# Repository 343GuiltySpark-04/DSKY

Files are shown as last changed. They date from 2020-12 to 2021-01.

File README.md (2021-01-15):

# DSKY

## This is a project where I make a replica of the DSKY (DiSplay and Keyboard assemblY) that works with ReEntry: an orbital simulator.

I am planning to sell these replicas. I have made functional prototypes of the display and keyboard, i just need to design pcb's to merge it all together, which i am currently doing.

## Guide on hooking up the PCB and installing the software

Preperation: hookup your arduino to your PC, download the repo in zip format and extract it, and enable the AGC output function in teh reentry settings (at the bottom).

# Step one: install python

Go to this link:

https://realpython.com/installing-python/

And follow the guide for your respective OS.

# Step two: edit the port.

Right click the JSON_export file, and edit with IDLE. First, check to what port your arduino is plugged in.
You can find the device manager by searching for it in Start. Then select Ports to display the list of ports. It should say Arduino (COMX).

Now, remember what number is behind the port. Go back to the script and edit where it says COM3 into what port yours is (COM1, COM2, etc).

# Step 3: Upload the code onto the arduino

Install the arduino IDE from the arduino website. Next, open the display.ino file from the display folder in the arduino IDE. Now, click on Tools > ports > and select
your correct port (the one you put in the script). Now, click on the upload button in  the top left. When its done, you can close the IDE. To use it now, you can run the python script in IDLE.

# Step 4: Hooking up the PCB

*WIP*

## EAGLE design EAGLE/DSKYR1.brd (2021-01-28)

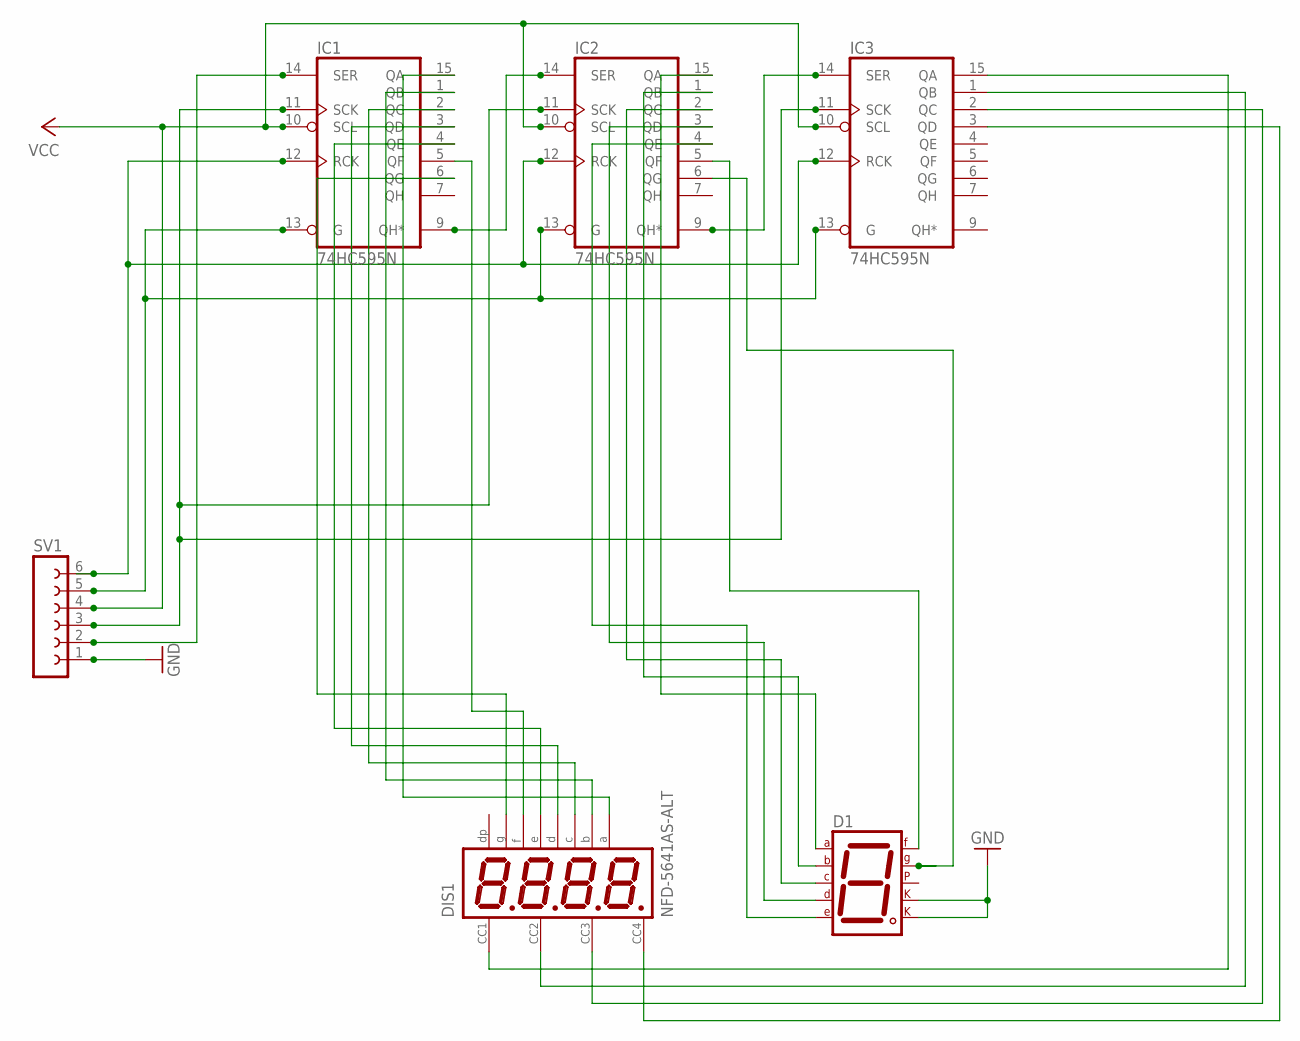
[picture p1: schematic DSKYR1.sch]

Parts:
D1: 7SEG-CK; 7SEG-13
DIS1: NFD-5641AS-ALT; NFD-5641
IC1, IC2, IC3: 74HC595N; DIL16
SV1: FE06-1; FE06

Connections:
GND: D1.3 (CK1), D1.8 (CK2), IC1.8 (GND), IC2.8 (GND), IC3.8 (GND), SV1.1
unnamed: IC1.12 (RCK), IC2.12 (RCK), IC3.12 (RCK), SV1.6
unnamed: DIS1.P$10, IC1.5 (QF)
unnamed: DIS1.P$5, IC1.6 (QG)
unnamed: IC1.13 (G), IC2.13 (G), IC3.13 (G), SV1.5
unnamed: IC1.14 (SER), SV1.2
unnamed: IC1.9 (QH*), IC2.14 (SER)
unnamed: IC1.11 (SCK), IC2.11 (SCK), IC3.11 (SCK), SV1.3
unnamed: IC2.9 (QH*), IC3.14 (SER)
unnamed: DIS1.P$11, IC1.15 (QA)
unnamed: DIS1.P$7, IC1.1 (QB)
unnamed: DIS1.P$4, IC1.2 (QC)
unnamed: DIS1.P$2, IC1.3 (QD)
unnamed: DIS1.P$1, IC1.4 (QE)
unnamed: D1.7 (A), IC2.15 (QA)
unnamed: D1.6 (B), IC2.1 (QB)
unnamed: D1.4 (C), IC2.2 (QC)
unnamed: D1.2 (D), IC2.3 (QD)
unnamed: D1.1 (E), IC2.4 (QE)
unnamed: D1.9 (F), IC2.5 (QF)
unnamed: D1.10 (G), IC2.6 (QG)
unnamed: DIS1.P$12, IC3.15 (QA)
unnamed: DIS1.P$9, IC3.1 (QB)
unnamed: DIS1.P$8, IC3.2 (QC)
unnamed: DIS1.P$6, IC3.3 (QD)
VCC: IC1.10 (SCL), IC1.16 (VCC), IC2.10 (SCL), IC2.16 (VCC), IC3.10 (SCL), IC3.16 (VCC), SV1.4

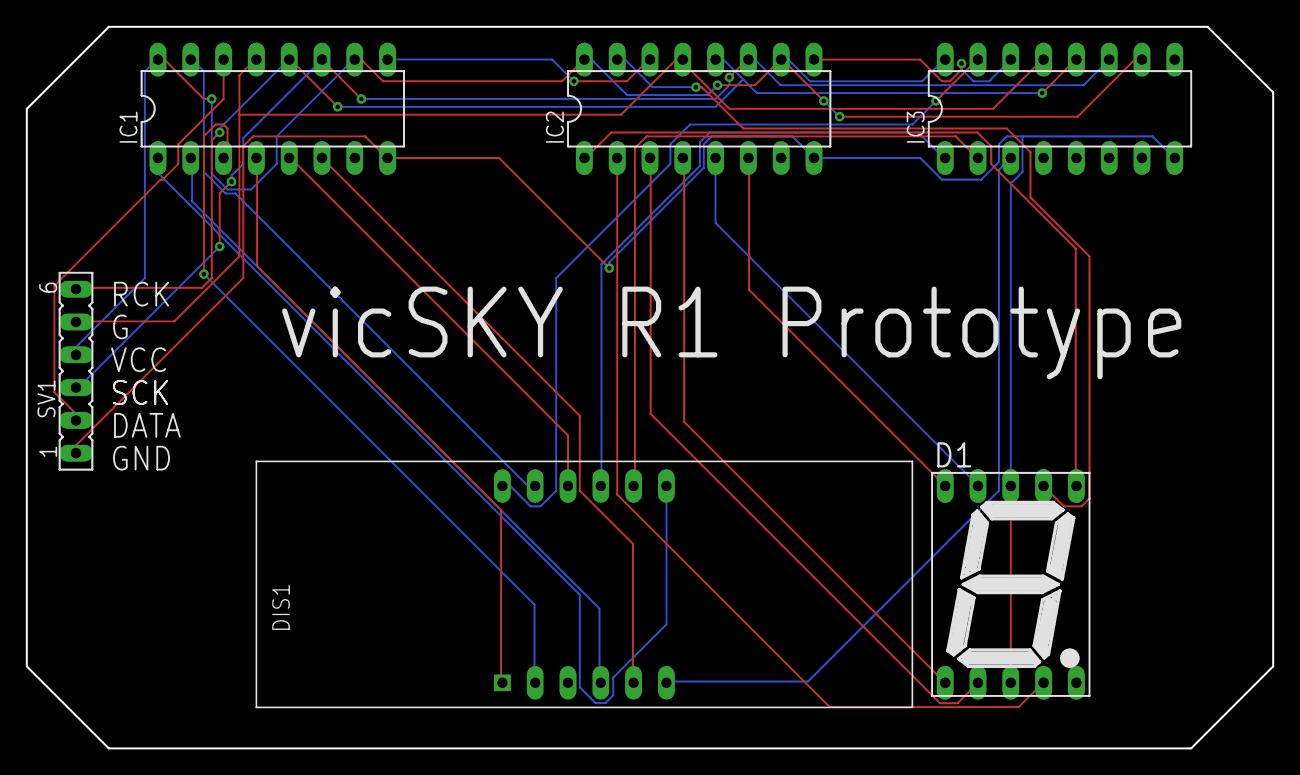
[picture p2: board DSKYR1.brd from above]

Board: 2 copper layers, 96.5 x 55.9 mm, 6 parts (0 on the bottom side), 26 nets.

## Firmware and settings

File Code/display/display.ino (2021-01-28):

int latchPin = 11;
int clockPin = 9;
int dataPin = 12;
byte first;
byte second;
byte third;

char R1D1;
char R1D2;
char R1D3;
char R1D4;
char R1D5;


const byte numChars = 64;
char receivedChars[numChars];

void updateShiftRegister(){
  digitalWrite(latchPin, LOW);
  
  shiftOut(dataPin, clockPin, LSBFIRST, first);
  shiftOut(dataPin, clockPin, LSBFIRST, second);  
  shiftOut(dataPin, clockPin, LSBFIRST, third);  
  digitalWrite(latchPin, HIGH);
}



void setup(){
  pinMode(latchPin, OUTPUT);
  pinMode(dataPin, OUTPUT);
  pinMode(clockPin, OUTPUT);
  Serial.begin(9600);
  
}

void setNumber(char num){
  if (num == '1'){
    third = 0b01100000;
    second = 0b01100000;
  }

  if (num == '2'){
    third = 0b11011011;
    second = 0b11011011;
  }

  if (num == '3'){
    third = 0b11110011;
    second = 0b01100000;
  }

  if (num == '4'){
    third = 0b01100111;;
    second = 0b01100111;;
  }

  if (num == '5'){
    third = 0b10110111;
    second = 0b10110111;
  }

  if (num == '6'){
    third = 0b10111111;
    second = 0b10111111;
  }

  if (num == '7'){
    third = 0b11100001;
    second = 0b11100001;
  }
  if (num == '8'){
    third = 0b11111111;
    second = 0b11111111;
  }
  if (num == '9'){
    third = 0b11100111;
    second = 0b11110111;
  }
  if (num == '0'){
    third = 0b11111101;
    second = 0b11111101;
  }
}


void recvWithStartEndMarkers() {
    static boolean recvInProgress = false;
    static byte ndx = 0;
    char startMarker = '<';
    char endMarker = '>';
    char rc;

    while (Serial.available() > 0) {
        rc = Serial.read();

        if (recvInProgress == true) {
            if (rc != endMarker) {
                receivedChars[ndx] = rc;
                ndx++;
                if (ndx >= numChars) {
                    ndx = numChars - 1;
                }
            }
            else {
                receivedChars[ndx] = '\0'; // terminate the string
                recvInProgress = false;
                ndx = 0;
                
            }
        }

        else if (rc == startMarker) {
            recvInProgress = true;
        }
    }
}

void loop(){
  recvWithStartEndMarkers();
  ControlDisplay();  
  
}

void ControlDisplay(){
  
  R1D5=receivedChars[5];
  R1D4=receivedChars[3];
  R1D3=receivedChars[2];
  R1D2=receivedChars[1];
  R1D1=receivedChars[0];
   
  first = 0b01111111;
  setNumber(R1D5);
  updateShiftRegister();
  delay(1);
  first = 0b10111111;
  setNumber(R1D2);
  updateShiftRegister();
  delay(1);
  first = 0b11011111;
  setNumber(R1D3);
  updateShiftRegister();
  delay(1);
  first = 0b11101111;
  setNumber(R1D4);
  updateShiftRegister();
  delay(1);
  first = 0b11110111;
  setNumber(R1D1);
  updateShiftRegister();
  delay(1);
 
}

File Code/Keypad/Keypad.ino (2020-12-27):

#include <Keypad.h>

const int ROW_NUM = 3; //four rows
const int COLUMN_NUM = 5; //three columns

char keys[ROW_NUM][COLUMN_NUM] = {
  {'+','9','8','7','c'},
  {'-','6','5','4','p'},
  {'0','3','2','1','k'}  
};

byte pin_rows[ROW_NUM] = {11, 10, 9}; //connect to the row pinouts of the keypad
byte pin_column[COLUMN_NUM] = {6, 5, 4, 3, 2}; //connect to the column pinouts of the keypad

Keypad keypad = Keypad( makeKeymap(keys), pin_rows, pin_column, ROW_NUM, COLUMN_NUM );

void setup(){
  Serial.begin(9600);
}

void loop(){
  char key = keypad.getKey();

  if (key){
    Serial.print(key);
    delay(200);
  }
}

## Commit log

2020-12-27 Reorganize, and add EAGLE files
    [DSKY.brd, DSKY.sch]
2020-12-27 Update shit
    [DSKY.brd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]
2020-12-27 Update BRD
    [DSKY.brd, DSKY.sch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]
2021-01-12 Rework PCB and schematic
    [DSKY.brd, DSKY.sch, DSKYR1.brd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]
2021-01-15 Update guide, finalize gerber files
    [DSKYR1.brd, DSKYR1.sch]
2021-01-22 Update display.ino
    pushed the wrong file lol
    [display.ino]
2021-01-22 Connect ground lines of R1D5
    [DSKYR1.brd, DSKYR1.sch]
